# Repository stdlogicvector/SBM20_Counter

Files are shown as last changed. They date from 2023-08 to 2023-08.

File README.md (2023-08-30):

# SBM20 Counter

With this PCB and an SBM20 tube you can build a small, battery operated geiger counter. It can be supplied by two AA batteries, for example. Depending on the battery type you can populate the Step-Up (<5V) or the Step-Down (>5V).
The left part of the PCB generates the approx. 400V for the tube, the right part amplifies and shapes the pulses for the LED and buzzer.
The buzzer is optional if the LED is sufficient feedback.



## Acknowledgements
The circuit is bodged together from multiple sources on the internet, mainly from [MightyOhm](https://mightyohm.com/files/geiger/geiger_sch_fixedR5R6.png).

## Contact
Send Questions to @stdlogicvector@chaos.social 

## BOM

| **Qty** | **Value** | **Footprint** | **Parts** | **DIGIKEY** | **LCSC** |
| --- | --- | --- | --- | --- | --- |
| 1 | Red | CHIPLED_1206 | LED | | |
| 1 | 100R | R-TRIMM3224J | R14 | | |
| 1 | 1M | R-EU_R1206 | R2 | | |
| 2 | 1N4148 | SOD123 | D2, D3 | | |
| 2 | 1k | R-EU_R0603 | R13, R32 | | |
| 1 | 1k5 | R-EU_R0603 | R1 | | |
| 2 | 1n | C-EUC0603 | C3, C6 | | |
| 1 | 1u | C-EUC1206 | C9 | | |
| 1 | 2u2 | C-EUC1206 | C10A | | |
| 1 | 4M7 | R-EU_R1206 | R10 | | |
| 1 | 4k7 | R-EU_R0603 | R9 | | |
| 1 | 10mH | L-EUL8065 | L1 | | |
| 2 | 10n 630V  | C-EUC1206 | C1, C5 | | |
| 4 | 10u | C-EUC1206 | C8, C8A, C8B, C10 | | |
| 1 | 20p | C-EUC0603 | C11 | | |
| 1 | 22R | R-EU_R0603 | R5 | | |
| 1 | 27k | R-EU_R0603 | R4 | | |
| 1 | 30R | R-EU_R0603 | R5A | | |
| 3 | 100k | R-EU_R0603 | R7, R11, R12 | | |
| 2 | 100n | C-EUC0603 | C2, C7 | | |
| 1 | 120k | R-EU_R0603 | R16 | | |
| 1 | 180k | R-EU_R0603 | R6 | | |
| 1 | 220k | R-EU_R0603 | R3 | | |
| 1 | 220p | C-EUC0603 | C4 | | |
| 1 | 330R | R-EU_R0603 | R8 | | |
| 1 | 680k | R-EU_R0603 | R15 | | |
| 1 | CMMR1U-06 | DO-214AC | D1 | 1514-CMMR1U-06TRPBFREECT-ND |
| 1 | DN350T05  | SOT23 | T1 | DN350T05DICT-ND |
| 1 | LM555D | LM555D | IC2 | LM555CMX/NOPBCT-ND |
| 1 | LM556D | LM556D | IC1 | 2156-LM556CM-FS-ND |
| 2 | MMBT3904  | SOT23 | T2, T3 | 4530-MMBT3904CT-ND |
| 2 | SBM20 | FUSECLIP | SBM20 | F3781-ND | |
| 1 | XC914X | SOT23-5 | IC3 | 893-1373-1-ND | |
| 1 | XC926X | SOT23-5 | IC3A | 893-1330-1-ND | |
| 2 | 4u7 | L5050 | L2, L2A | 490-7779-1-ND | |
| 1 | KJL-5020  | BUZZER-5020 | BEEP | | C556937  |
| 1 | AO3404A | SOT23 | T6 | | C30010 |
| 1 | | SWITCH-SPDT-SMD-A | PWR | | C319019  |

The SMB20 tube is available from several ebay sellers.

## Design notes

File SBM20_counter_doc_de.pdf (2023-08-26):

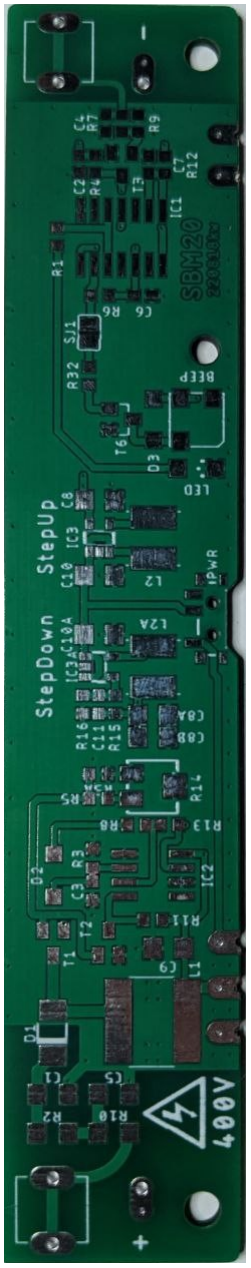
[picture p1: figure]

# SMB20 Geigerzähler

## Mit dieser kleinen Platine und einem SBM20 Zählrohr lässt sich ein

handlicher, batteriebetriebener Geigerzähler aufbauen. Er kann z.B.

## durch zwei AA-Batterien versorgt werden. Je nach gewähltem Batterietyp kann der Step-Up (<5V) [A2] oder der Step-Down (>5V)

[A4] bestückt werden.

## Der untere Teil der Platine erzeugt die ca. 400V für das Zählrohr, der

obere Teil verstärkt und formt die Pulse und generiert die Piepstöne. Der Buzzer [D1/D2] kann unbestückt bleiben, falls die LED ausreicht.

## Bei Fragen: @stdlogicvector@chaos.social

Qty | Value | Footprint | Parts | DIGIKEY | LCSC
1 | Red | CHIPLED_1206 | LED
1 | 100R | R-TRIMM3224J | R14
1 | 1M | R-EU_R1206 | R2
2 | 1N4148 | SOD123 | D2, D3
2 | 1k | R-EU_R0603 | R13, R32
1 | 1k5 | R-EU_R0603 | R1
2 | 1n | C-EUC0603 | C3, C6
1 | 1u | C-EUC1206 | C9
1 | 2u2 | C-EUC1206 | C10A
1 | 4M7 | R-EU_R1206 | R10
1 | 4k7 | R-EU_R0603 | R9
1 | 10mH | L-EUL8065 | L1
2 | 10n 630V | C-EUC1206 | C1, C5
4 | 10u | C-EUC1206 | C8, C8A, C8B, C10
1 | 20p | C-EUC0603 | C11
1 | 22R | R-EU_R0603 | R5
1 | 27k | R-EU_R0603 | R4
1 | 30R | R-EU_R0603 | R5A
3 | 100k | R-EU_R0603 | R7, R11, R12
2 | 100n | C-EUC0603 | C2, C7
1 | 120k | R-EU_R0603 | R16
1 | 180k | R-EU_R0603 | R6
1 | 220k | R-EU_R0603 | R3
1 | 220p | C-EUC0603 | C4
1 | 330R | R-EU_R0603 | R8
1 | 680k | R-EU_R0603 | R15
1 | CMMR1U-06 DO-214AC | D1
| | | | 1514-CMMR1U- 06TRPBFREECT-ND
1 | DN350T05 | SOT23 | T1 | DN350T05DICT-ND
1 | LM555D | LM555D | IC2 | LM555CMX/NOPBCT-ND
1 | LM556D | LM556D | IC1 | 2156-LM556CM-FS-ND
2 | MMBT3904 | SOT23 | T2, T3 | 4530-MMBT3904CT-ND
2 | SBM20 | FUSECLIP | SBM20 | F3781-ND
1 | XC914X | SOT23-5 | IC3 | 893-1373-1-ND
1 | XC926X | SOT23-5 | IC3A | 893-1330-1-ND
2 | 4u7 | L5050 | L2, L2A | 490-7779-1-ND
1 | KJL-5020 | BUZZER-5020 | BEEP | C556937
1 | AO3404A | SOT23 | T6 | C30010
1 | | SWITCH-SPDT-SMD-A PWR | | | C319019

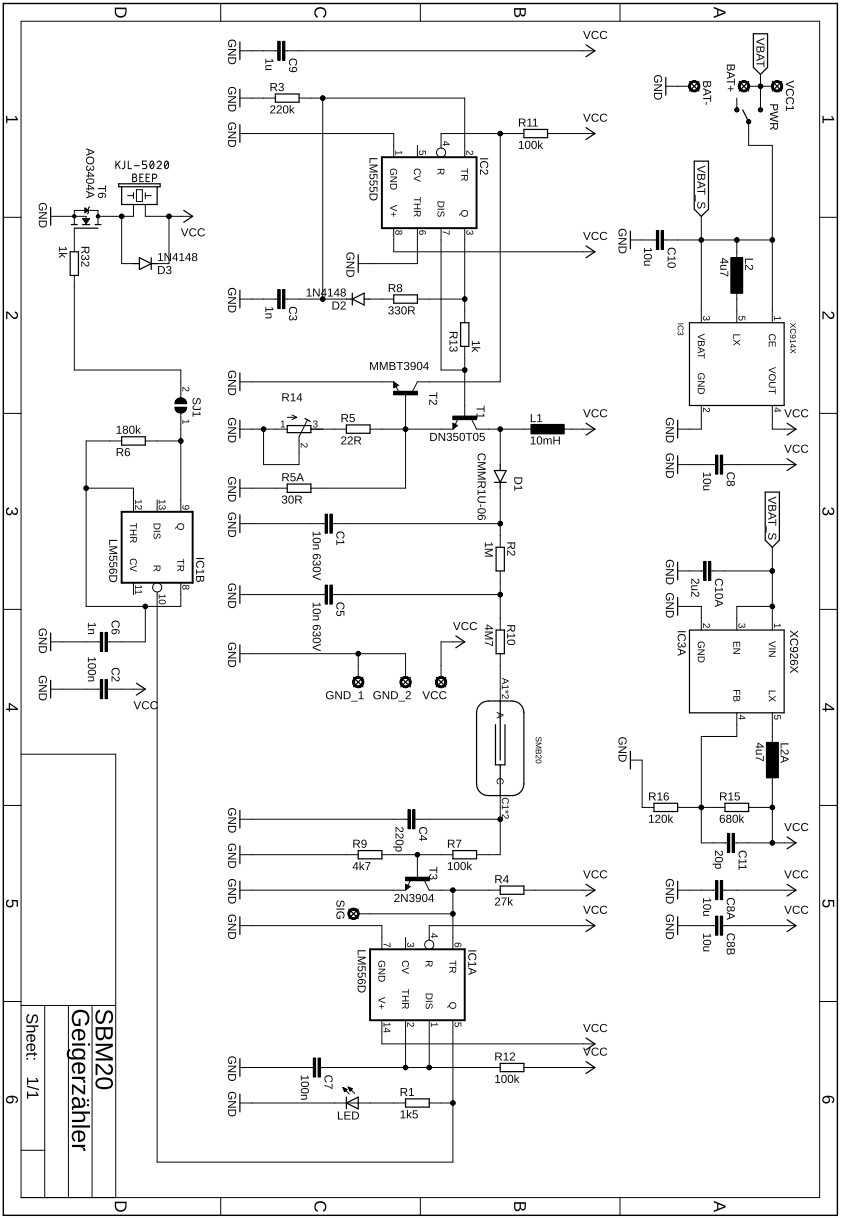
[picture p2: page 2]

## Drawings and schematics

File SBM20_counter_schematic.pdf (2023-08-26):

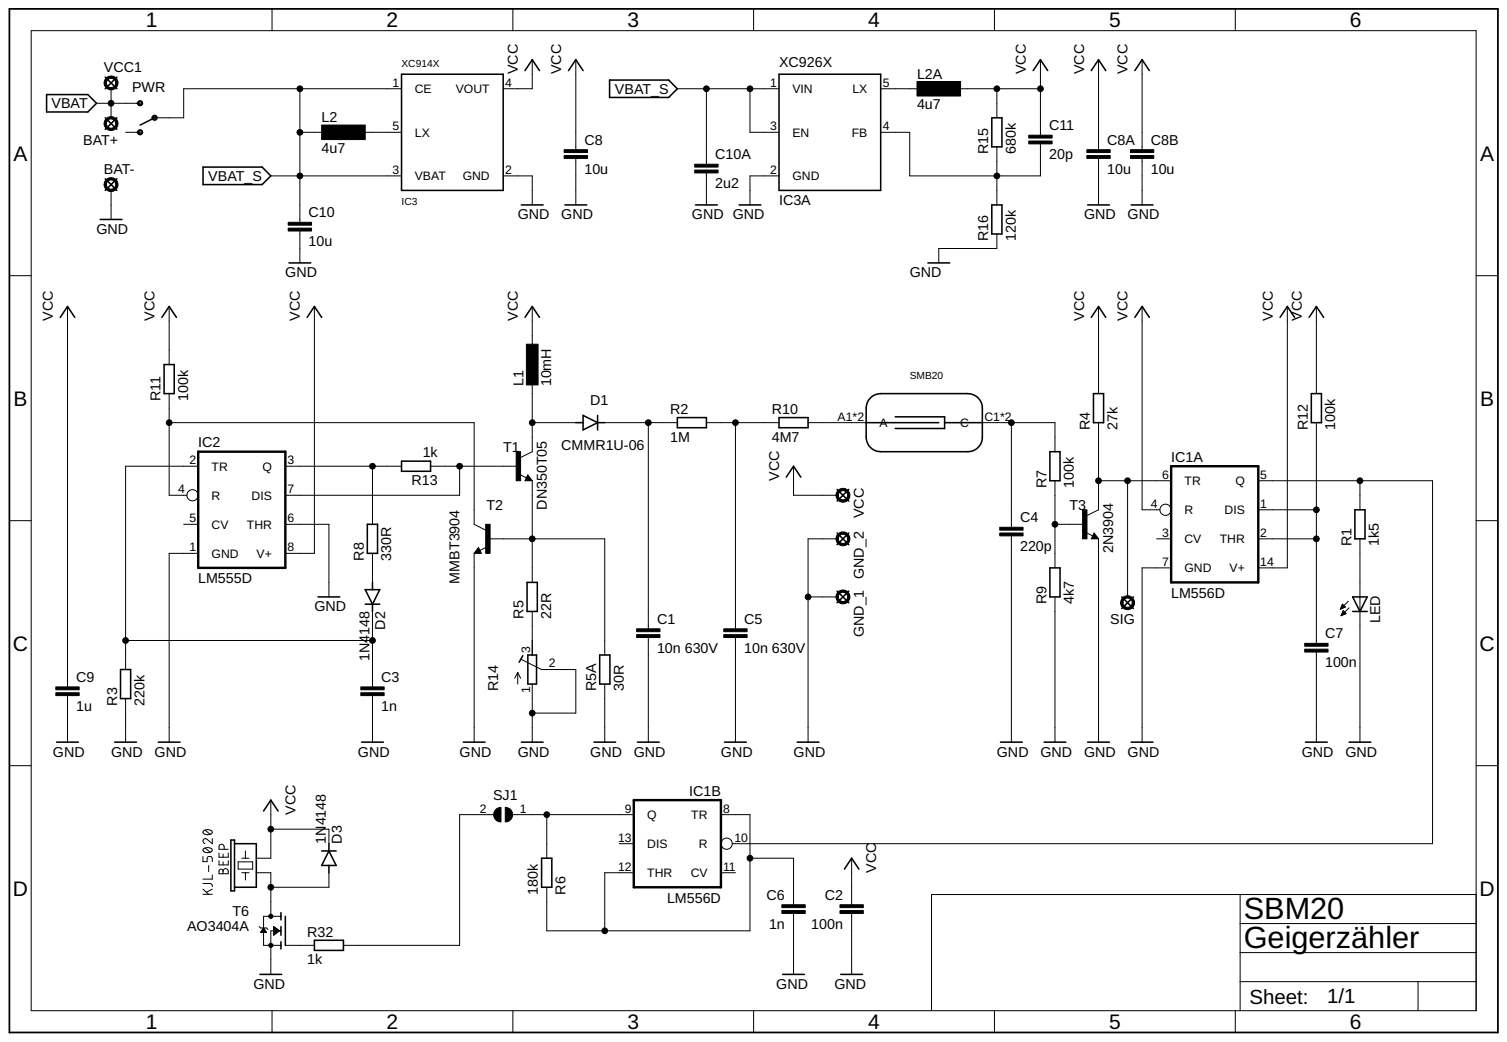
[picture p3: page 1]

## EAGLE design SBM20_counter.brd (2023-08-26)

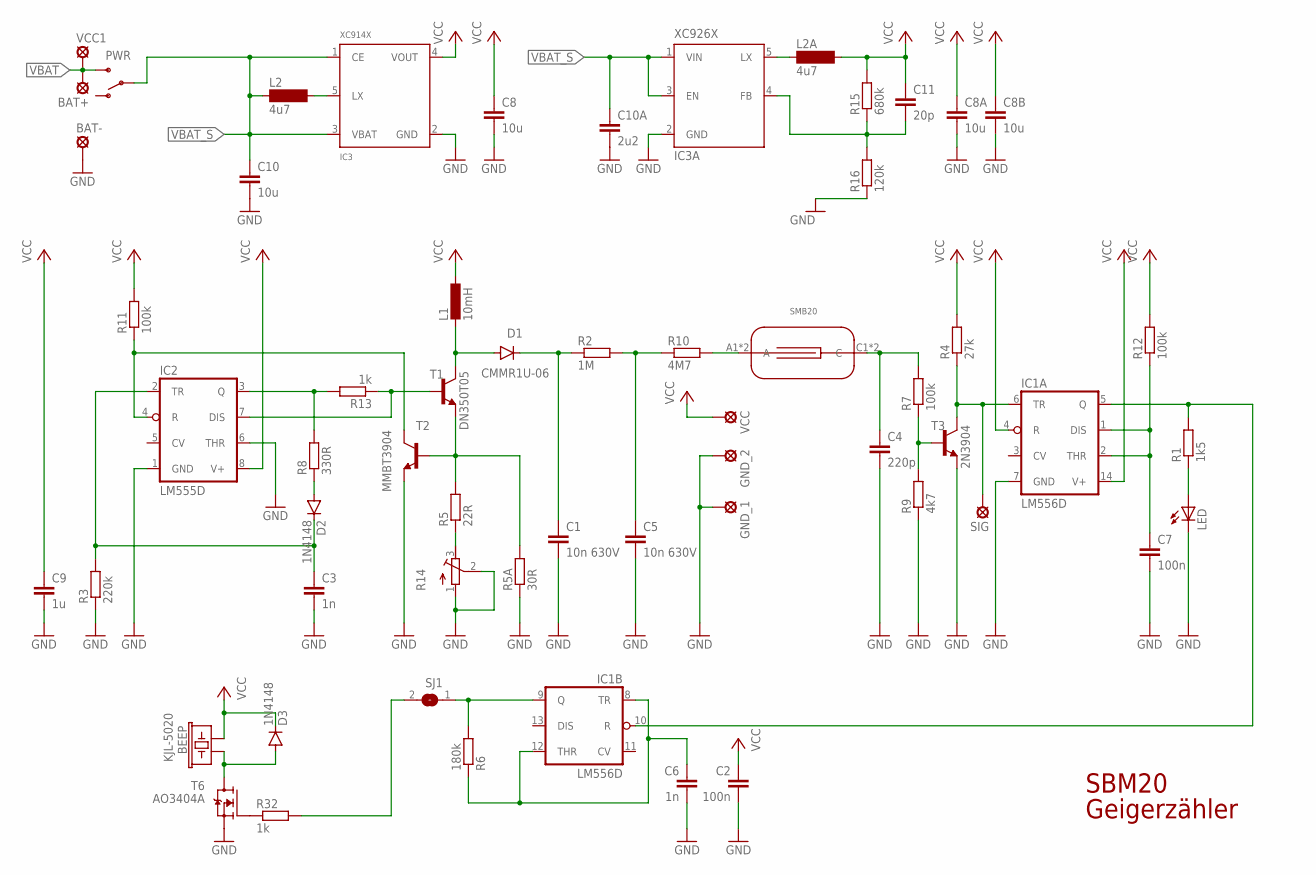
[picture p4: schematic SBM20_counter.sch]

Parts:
BAT+: LSP10_CAST; CASTEL_1
BAT-: LSP10_CAST; CASTEL_1
BEEP: KJL-5020; KLJ-5020; LCSC C556937
C1, C5: 10n 630V; C1206
C2, C7: 100n; C0603
C3, C6: 1n; C0603
C4: 220p; C0603
C8, C8A, C8B, C10: 10u; C1206
C9: 1u; C1206
C10A: 2u2; C1206
C11: 20p; C0603
D1: CMMR1U-06; DO-214AC
D2, D3: 1N4148; SOD123
GND_1, GND_2: LSP10_CAST; CASTEL_1
IC1: LM556D; SO14
IC2: LM555D; SO08
IC3: XC914X; SOT23-5; DIGIKEY 893-1373-1-ND
IC3A: XC926X; SOT23-5; DIGIKEY 893-1330-1-ND
L1: 10mH; L8065
L2, L2A: 4u7; L5050; DIGIKEY 490-7779-1-ND
LED: LEDCHIPLED_1206; CHIPLED_1206
PWR: SWITCH-SPDT-SMD-A; SWITCH-SPST-SMD-A; LCSC C319019
R1: 1k5; R0603
R2: 1M; R1206
R3: 220k; R0603
R4: 27k; R0603
R5: 22R; R0603
R5A: 30R; R0603
R6: 180k; R0603
R7, R11, R12: 100k; R0603
R8: 330R; R0603
R9: 4k7; R0603
R10: 4M7; R1206
R13: 1k; R0603
R14: R-TRIMM3224J; RTRIM3224J
R15: 680k; R0603
R16: 120k; R0603
R32: 1k; R0603; LCSC C11702
SIG: LSP10_CAST; CASTEL_1
SJ1: SJ
T1: DN350T05; SOT23-BEC
T2: MMBT3904; SOT23-BEC
T3: 2N3904; SOT23-BEC
T6: AO3404A; SOT23; LCSC C30010
U$1: SMB20; STS5
VCC, VCC1: LSP10_CAST; CASTEL_1

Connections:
GND: BAT-.C, BAT-.V, C1.2, C2.2, C3.2, C4.2, C5.2, C6.2, C7.2, C8.2, C8A.2, C8B.2, C9.2, C10.2, C10A.2, GND_1.C, GND_1.V, GND_2.C, GND_2.V, IC1.7 (GND), IC2.1 (GND), IC2.6 (THR), IC3.2 (GND), IC3A.2 (GND), LED.C, R3.1, R5A.1, R9.1, R14.1 (A), R14.2 (S), R16.1, T2.E, T3.E, T6.2 (S)
unnamed: R5.2, R5A.2, T1.E, T2.B
unnamed: IC2.3 (Q), R8.2, R13.2
unnamed: C3.1, D2.C, IC2.2 (TR), R3.2
unnamed: IC2.4 (R), R11.1, T2.C
unnamed: IC2.7 (DIS), R13.1, T1.B
unnamed: D2.A, R8.1
unnamed: R5.1, R14.3 (E)
unnamed: D1.A, L1.2, T1.C
unnamed: C1.1, D1.C, R2.1
unnamed: C5.1, R2.2, R10.1
unnamed: R10.2, U$1.A1 (A), U$1.A2 (A)
unnamed: C4.1, R7.2, U$1.C1 (C), U$1.C2 (C)
unnamed: R7.1, R9.2, T3.B
unnamed: IC1.6 (TR), R4.1, SIG.C, SIG.V, T3.C
unnamed: IC1.5 (Q), IC1.10 (R), R1.2
unnamed: C7.1, IC1.1 (DIS), IC1.2 (THR), R12.1
unnamed: IC1.9 (Q), R6.2, SJ1.1
unnamed: LED.A, R1.1
unnamed: R32.2, SJ1.2
unnamed: IC3A.5 (LX), L2A.1
unnamed: C6.1, IC1.8 (TR), IC1.12 (THR), R6.1
unnamed: IC3.5 (LX), L2.2
unnamed: C11.2, IC3A.4 (FB), R15.1, R16.2
unnamed: R32.1, T6.1 (G)
unnamed: BEEP.- (2), D3.A, T6.3 (D)
VBAT: BAT+.C, BAT+.V, PWR.3 (S), VCC1.C, VCC1.V
VBAT_S: C10.1, C10A.1, IC3.1 (CE), IC3.3 (VBAT), IC3A.1 (VIN), IC3A.3 (EN), L2.1, PWR.2
VCC: BEEP.+ (1), C2.1, C8.1, C8A.1, C8B.1, C9.1, C11.1, D3.C, IC1.4 (R), IC1.14 (V+), IC2.8 (V+), IC3.4 (VOUT), L1.1, L2A.2, R4.2, R11.2, R12.2, R15.2, VCC.C, VCC.V

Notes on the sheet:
SBM20
Geigerzähler

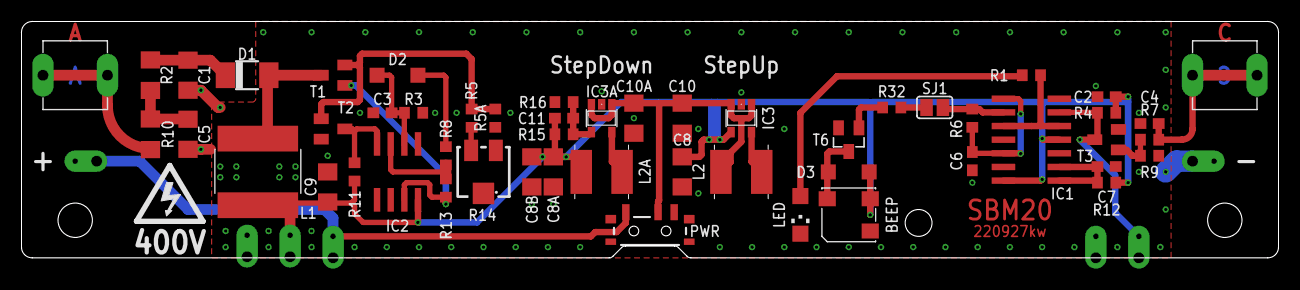
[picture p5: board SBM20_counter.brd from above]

Board: 2 copper layers, 117.0 x 22.0 mm, 59 parts (0 on the bottom side), 29 nets.

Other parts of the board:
U$2: HIGHVOLTAGE

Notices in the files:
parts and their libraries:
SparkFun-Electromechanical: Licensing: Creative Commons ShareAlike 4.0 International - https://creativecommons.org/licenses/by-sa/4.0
